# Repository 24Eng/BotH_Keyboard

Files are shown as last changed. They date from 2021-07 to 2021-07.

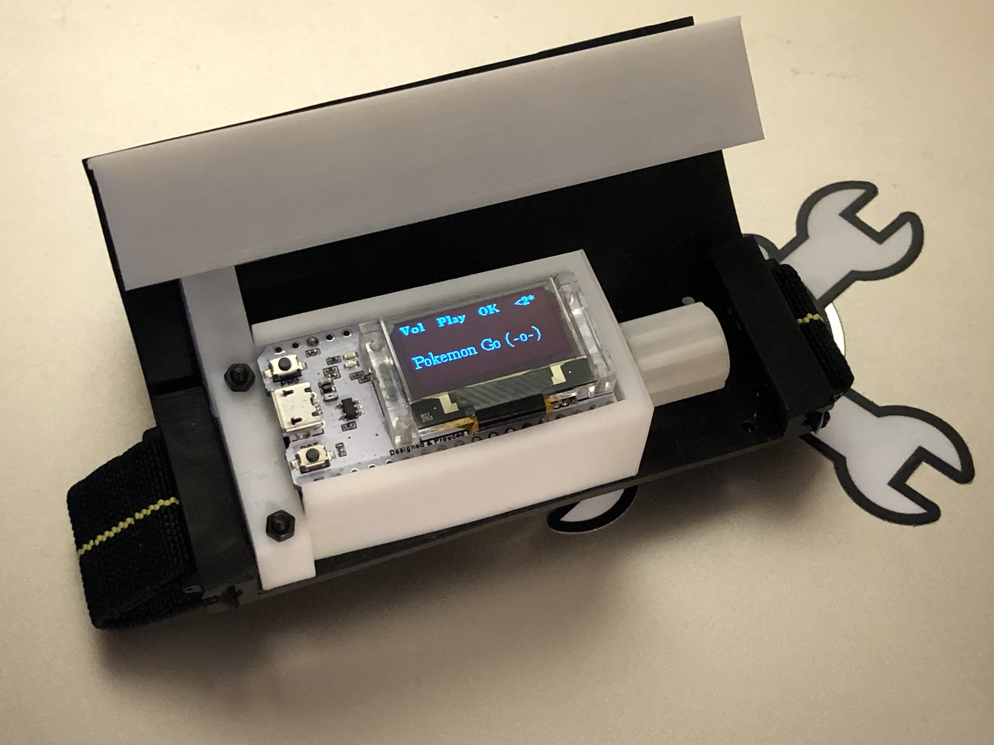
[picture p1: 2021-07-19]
2021-07-18 18.53.59.jpg

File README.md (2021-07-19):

# BotH_Keyboard
http://www.24hourengineer.com/search?q=%22BackOfTheHand%22&max-results=20&by-date=true

I use macros at work and home all the time, but sometimes pressing shift + alt + control + W or some other hard-to-remember combination isn't the best. Gamers have used off-hand keyboards for a while, and I love mine, but they're only helpful if you're at your battle station. I have seen folks put macro buttons on a footstool and use their toes, and that kind of ingenuity got me thinking. I wanted to keep my hands free and add wireless flexibility. Leveraging my experience with wearables, I got BOTH. 

The Back of the Hand keyboard gives me four programmable buttons by extending a finger backward. I can twist a screwdriver and pause the music on my phone or hold an electrical probe and command the computer to activate a test point.

Four is not a lot, so the wheel lets me change layers without fuss. I can go from obscure keyboard buttons to Pokemon Go (-o-) in a second. The case is entirely 3D printed. It accepts standard Cherry MX keyswitches so that you can choose clicky or silent operation. It uses an Apple Watch band so that you can choose any color. I like the black elastic, but the stainless Milanese looks sharp.

I would probably use a larger battery if I built a second one, but it is still possible to use this while connected to any USB charger. The core is an ESP32 and uses Bluetooth Low-Energy to emulate a keyboard.

My build log is at 24hourengineer.com. 

Helpful links and library sources
TTGO ESP32 module
https://github.com/Xinyuan-LilyGO/TTGO-T-Display

ESP32 module links
https://robotzero.one/heltec-wifi-kit-32/
https://github.com/Heltec-Aaron-Lee/WiFi_Kit_series

Display drivers
https://github.com/olikraus/u8g2

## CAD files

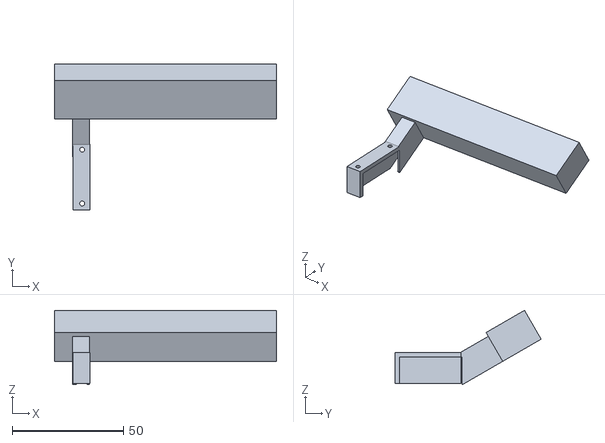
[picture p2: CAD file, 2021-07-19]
2021-07-15_WearableMacroKeyboard_Cover.stl
100.0 x 65.9 x 33.5

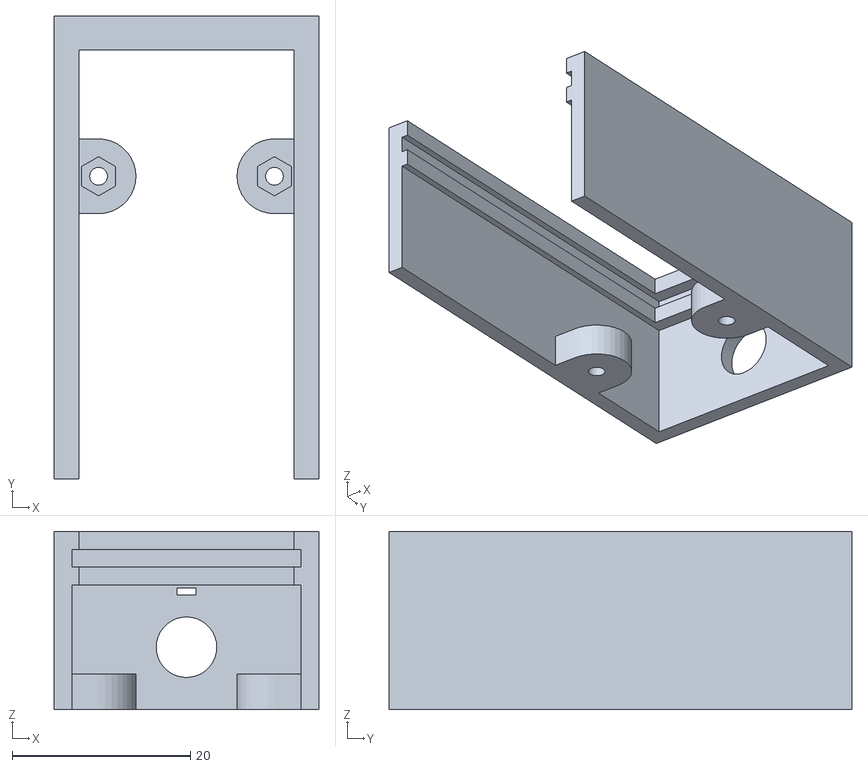
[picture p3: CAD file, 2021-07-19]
2021-06-22_BoardHolder.stl
29.8 x 52.0 x 20.0

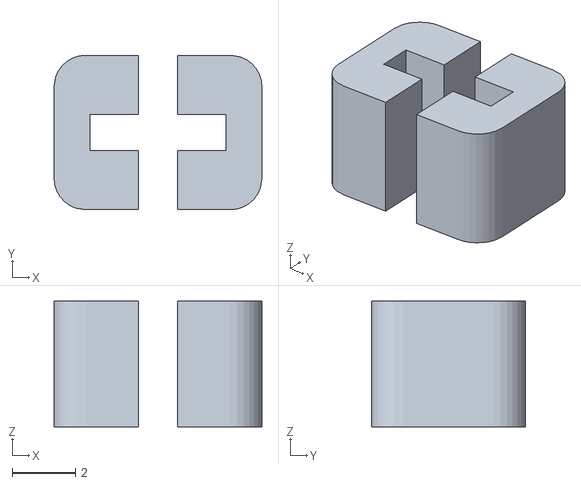
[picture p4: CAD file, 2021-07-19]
rsheldiii_keycap_stem.stl
6.60 x 4.90 x 3.99

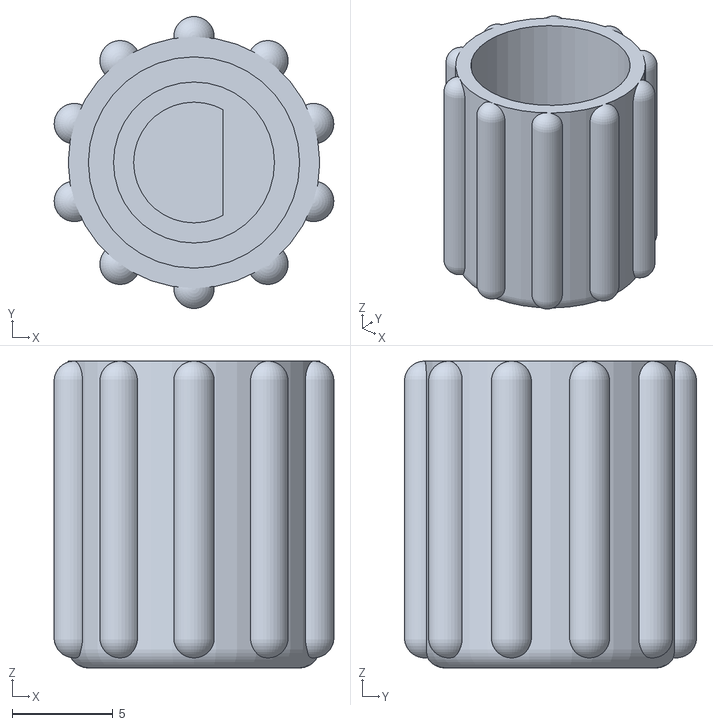
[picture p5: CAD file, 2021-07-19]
2021-06-22_EncoderKnob.stl
13.9 x 14.5 x 15.2

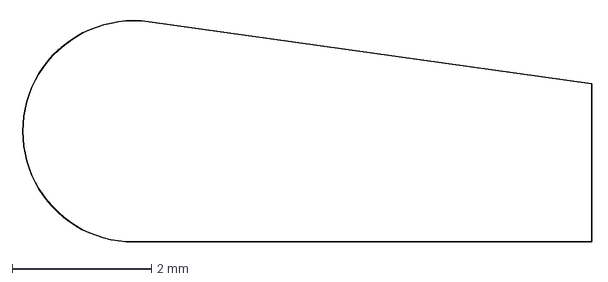
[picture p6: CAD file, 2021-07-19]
AppleWatchCavity.dxf
8.28 x 3.25 mm

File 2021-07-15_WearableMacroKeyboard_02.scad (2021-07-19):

// WearableMacroKeyboard by 24Eng
printSelection = 0;
thickness = 2;
platformThickness = 3;
palmWidth = 80;
fingerDistance = 25;
boltDiameter = 2;
boltHeadDiameter = 4.5;
boltHeadThickness = 1.5;
nutMajorDiameter = 4.4;
printerSlop = 0.1;
keyswitchHoleLength = 0.551 * 25.4;
keyswitchHoleWidth = 0.551 * 25.4;
keyswitchHoleThickness = 0.06 * 25.4;
keyswitchLength = 15.6;
keyswitchWidth = 15.6;
keyswitchThickness = 10;
watchBandLength = 31+thickness;
fingerPadSlope = 30;
keycapForwardDistance = 30;

BHLength = 50;
BHWidth = 25.75;
BHThickness = 2;
BHEdge = 0.8;
BHClearance = 12;
BHBoltDiameter = boltDiameter;
BHNutMajorDiameter = nutMajorDiameter;
BHMountOffset = 8;

boltRadius = boltDiameter/2 + printerSlop;
boltHeadRadius = boltHeadDiameter/2 + printerSlop;
nutMajorRadius = nutMajorDiameter / 2 + printerSlop;
platformWidth = (fingerDistance)*4;
platformLength = watchBandLength;
watchBandThickness = 8;


//$vpr = [70,0,55+360 * $t];
//$vpd = 150;
//$vpr = [55,0,25];
//$vpr = [90,0,0];
//$vpt = [0,0,10];
$fn=36;

if(printSelection == 0){
    color("powderblue"){
        // This platform portion touches the back of the palm (Metacarpals)
        MetacarpalPlatform();
        
        // This portion hovers over the fingers (proximal phalanges)
        ProximalPlatform();
        
//        // A cylinder at the joining area should keep the two platform halves from fracturing
//        translate([-platformWidth/2,platformLength/2,0]){
//            rotate([0,90,0]){
//                #cylinder(platformWidth, thickness/2, thickness/2);
//            }
//        }
        
    }
        // The board holder will support the microcontroller
    translate([-BHMountOffset,0,thickness/2]){
        rotate([0,0,270]){
            difference(){
                BoardHolder();
                translate([0,BHLength/2,BHClearance/2+BHThickness/2]){
                    rotate([90,0,0]){
                        EncoderHole();
                    }
                }
            }
        }
    }
    color("violet"){
        translate([-(BHWidth+BHMountOffset+watchBandThickness),-BHWidth/2-BHThickness,thickness/2]){
            difference(){
                translate([0,0,0]){
                    cube([platformWidth/2-BHWidth-BHMountOffset-watchBandThickness-0.5, BHWidth+BHThickness*2, BHClearance+BHThickness*1]);
                    translate([(platformWidth/-12),platformLength,thickness/2]){
                        rotate([fingerPadSlope,0,0]){
                            translate([0,keycapForwardDistance-12,0]){
                                difference(){
                                    cube([platformWidth, 20, 15]);
                                    translate([thickness,thickness,-0.01]){
                                        cube([platformWidth-thickness*2, 20-thickness*2, 15-thickness*2]);
                                    }
                                    translate([10,-2,0]){
                                        cube([platformWidth/2-BHWidth-BHMountOffset-watchBandThickness-1.5-thickness, thickness*3, BHClearance-thickness]);
                                    }
                                }
                            }
                        }
                    }
                    translate([(platformWidth/-12)+8,platformLength,thickness/2]){
                        rotate([fingerPadSlope,0,0]){
                            translate([0,-3,0]){
                                difference(){
                                    cube([platformWidth/2-BHWidth-BHMountOffset-watchBandThickness-0.5, BHWidth-4, BHClearance+1]);
                                   translate([thickness,0,0]){
                                       cube([platformWidth/2-BHWidth-BHMountOffset-watchBandThickness-1.5-thickness, BHWidth+BHThickness*1, BHClearance]);
                                   }
                                }
                            }
                        }
                    }
                }
                translate([(platformWidth/2-BHWidth-BHMountOffset-watchBandThickness)/2,thickness*1.5,0]){
                    cylinder(BHClearance*3, boltRadius, boltRadius, center=true);
                }
                translate([(platformWidth/2-BHWidth-BHMountOffset-watchBandThickness)/2,BHWidth+BHThickness*0.75,0]){
                    cylinder(BHClearance*3, boltRadius, boltRadius, center=true);
                }
                translate([thickness+0.01,thickness+0.01,0]){
                    cube([platformWidth/2-BHWidth-BHMountOffset-watchBandThickness-thickness, BHWidth*1.1, BHClearance]);
                }
            }
        }
    }
}

if(printSelection == 1){
    MetacarpalPlatform();
    ProximalPlatform();
}

if(printSelection == 2){
    color("violet"){
        translate([-(BHWidth+BHMountOffset+watchBandThickness),-BHWidth/2-BHThickness,thickness/2]){
            difference(){
                translate([0,0,0]){
                    cube([platformWidth/2-BHWidth-BHMountOffset-watchBandThickness-0.5, BHWidth+BHThickness*2, BHClearance+BHThickness*1]);
                    translate([(platformWidth/-12),platformLength,thickness/2]){
                        rotate([fingerPadSlope,0,0]){
                            translate([0,keycapForwardDistance-12,0]){
                                difference(){
                                    cube([platformWidth, 20, 15]);
                                    translate([thickness,thickness,-0.01]){
                                        cube([platformWidth-thickness*2, 20-thickness*2, 15-thickness*2]);
                                    }
                                    translate([10,-2,0]){
                                        cube([platformWidth/2-BHWidth-BHMountOffset-watchBandThickness-1.5-thickness, thickness*3, BHClearance-thickness]);
                                    }
                                }
                            }
                        }
                    }
                    translate([(platformWidth/-12)+8,platformLength,thickness/2]){
                        rotate([fingerPadSlope,0,0]){
                            translate([0,-3,0]){
                                difference(){
                                    cube([platformWidth/2-BHWidth-BHMountOffset-watchBandThickness-0.5, BHWidth-4, BHClearance+1]);
                                   translate([thickness,0,0]){
                                       cube([platformWidth/2-BHWidth-BHMountOffset-watchBandThickness-1.5-thickness, BHWidth+BHThickness*1, BHClearance]);
                                   }
                                }
                            }
                        }
                    }
                }
                translate([(platformWidth/2-BHWidth-BHMountOffset-watchBandThickness)/2,thickness*1.5,0]){
                    cylinder(BHClearance*3, boltRadius, boltRadius, center=true);
                }
                translate([(platformWidth/2-BHWidth-BHMountOffset-watchBandThickness)/2,BHWidth+BHThickness*0.75,0]){
                    cylinder(BHClearance*3, boltRadius, boltRadius, center=true);
                }
                translate([thickness+0.01,thickness+0.01,0]){
                    cube([platformWidth/2-BHWidth-BHMountOffset-watchBandThickness-thickness, BHWidth*1.1, BHClearance]);
                }
            }
        }
    }
}

if(printSelection == 3){
    difference(){
        BoardHolder();
        translate([0,BHLength/2,BHClearance/2+BHThickness/2]){
            rotate([90,0,0]){
                EncoderHole();
            }
        }
    }
}


// 24 Eng // Modules // 24 Eng // Modules // 24 Eng // Modules // 24 Eng // Modules 

module EncoderHole(){
    encoderShaftDiameter = 6.8;
    encoderShaftRadius = encoderShaftDiameter/2;
    encoderKeyWidth = 2.1;
    encoderKeyThickness = 0.8;
    encoderKeyOffset = 12.5/2;
    encoderPunctureDepth = 10;
    cylinder(encoderPunctureDepth, encoderShaftRadius, encoderShaftRadius, center=true);
    translate([0,encoderKeyOffset,0])cube([encoderKeyWidth,encoderKeyThickness,encoderPunctureDepth], center=true);
}

module CountersunkBolt(){
    cylinder(thickness*3, boltRadius, boltRadius, center=true);
    cylinder(thickness+0.001, boltHeadRadius, 0, center=true);
}
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

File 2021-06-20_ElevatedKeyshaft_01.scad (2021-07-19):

// The keycap stem is from rsheldii from their amazing
// keycap model.
// https://www.thingiverse.com/thing:468651


printSelector = 3;
shaftThickness = 7;
shaftHeight = 10;
boltDiameter = 2;
fingerPadDiameter = 15;
fingerPadThickness = 2;
nutMajorDiameter = 4.4;
nutThickness = 1.5;
washerThickness = 0.75;
keycapHeight = 14;
keycapAngle = 30;

nutMajorRadius = nutMajorDiameter/2;
fingerPadRadius = fingerPadDiameter/2;
boltRadius = boltDiameter/2;
shaftFillet = 1;
roundedShaftSide = shaftThickness - shaftFillet;
roundedShaftHeight = shaftHeight+1.001 - shaftFillet;
existingKeyshaftHeight = 3.99;

$fn = 36;
//$vpr = [70,0,25+$t*360];
$vpd = 100;
$vpt = [0,0,6];

if(printSelector == 0){
    color("red")KeyShaft();
    color("blue"){
        translate([0,0,existingKeyshaftHeight+shaftHeight+boltRadius+fingerPadThickness/2+fingerPadRadius/2]){
            rotate([180,0,0]){
                FingerPad();
            }
        }
    }
}

if(printSelector == 1){
    KeyShaft();
}

if(printSelector == 2){
    FingerPad();
}

if(printSelector == 3){
    RoundedKeycap(keycapHeight, keycapAngle);
}


// 24Eng // B.o.t.H. // Back of the Hand // Modules // 24Eng //
// 24Eng // B.o.t.H. // Back of the Hand // Modules // 24Eng //

module FingerPad(){
    cylinder(fingerPadThickness, fingerPadRadius, fingerPadRadius, center=true);
    rotate([0,0,0]){
        translate([shaftThickness/2+washerThickness,-fingerPadRadius/2,0]){
            difference(){
                translate([0,0,0]){
                    cube([fingerPadThickness, fingerPadRadius, fingerPadThickness/2+fingerPadRadius/2]);
                    translate([fingerPadThickness/2,fingerPadRadius/2,fingerPadRadius/2+fingerPadThickness/2]){
                        rotate([0,90,0]){
                            cylinder(fingerPadThickness, fingerPadRadius/2, fingerPadRadius/2, center=true);
                        }
                    }
                }
                translate([fingerPadThickness/2,fingerPadRadius/2,fingerPadRadius/2+fingerPadThickness/2]){
                    rotate([0,90,0]){
                        cylinder(fingerPadThickness*2, boltRadius, boltRadius, center=true);
                        translate([0,0,0])cylinder(nutThickness, nutMajorRadius, nutMajorRadius, $fn=6);
                    }
                }
            }
        }
    }
    rotate([0,0,180]){
        translate([shaftThickness/2+washerThickness,-fingerPadRadius/2,0]){
            difference(){
                translate([0,0,0]){
                    cube([fingerPadThickness, fingerPadRadius, fingerPadThickness/2+fingerPadRadius/2]);
                    translate([fingerPadThickness/2,fingerPadRadius/2,fingerPadRadius/2+fingerPadThickness/2]){
                        rotate([0,90,0]){
                            cylinder(fingerPadThickness, fingerPadRadius/2, fingerPadRadius/2, center=true);
                        }
                    }
                }
                translate([fingerPadThickness/2,fingerPadRadius/2,fingerPadRadius/2+fingerPadThickness/2]){
                    rotate([0,90,0]){
                        cylinder(fingerPadThickness*2, boltRadius, boltRadius, center=true);
                    }
                }
            }
        }
    }
}

module KeyShaft(){
    import("rsheldiii_keycap_stem.stl", convexity=10);
    difference(){
        translate([0,0,existingKeyshaftHeight + shaftHeight/2+boltDiameter*0.75]){
            minkowski(){
                cube([roundedShaftSide, roundedShaftSide, roundedShaftHeight+boltDiameter*1.5], center=true);
                cylinder(0.01, shaftFillet/2, shaftFillet/2, center=true);
            }
        }


        translate([0,0,existingKeyshaftHeight+shaftHeight+boltRadius]){
            rotate([0,90,0]){
                cylinder(shaftThickness*2, boltRadius, boltRadius, center=true);
            }
        }
    }
}

module RoundedKeycap(RKHeight, RKAngle){
    keyswitchSideLength = 15.6;
    keycapSideLength = keyswitchSideLength + 2*2;
    RKCavityDepth = 6.6 + 3.6 - 3.99;
    RKThickness = 2;
    RKRounding = 2;
    RKCylinderRadius = keyswitchSideLength/2;
    import("rsheldiii_keycap_stem.stl", convexity=10);
    difference(){
        translate([0,0,-RKCavityDepth/2+existingKeyshaftHeight+RKThickness]){
            minkowski(){
                cube([keycapSideLength, keycapSideLength, RKCavityDepth], center=true);
                sphere(RKRounding);
            }
        }
        translate([0,0,-RKCavityDepth/2+existingKeyshaftHeight-RKRounding/2]){
            minkowski(){
                cube([keycapSideLength-RKThickness, keycapSideLength-RKThickness, RKCavityDepth], center=true);
                sphere(RKRounding/2);
            }
        }
    }
    minkowski(){
        difference(){
            translate([0,0,existingKeyshaftHeight+RKRounding]){
                cylinder(RKHeight+RKCylinderRadius, RKCylinderRadius, RKCylinderRadius, center=false);
            }
            translate([0,0,existingKeyshaftHeight + RKHeight + RKCylinderRadius]){
                rotate([RKAngle,0,0]){
                    cube([RKCylinderRadius*6, RKCylinderRadius*6, RKCylinderRadius*2], center=true);
                }
            }
        }
        sphere(RKRounding);
    }
}





        translate([0,0,0]){
            
        }

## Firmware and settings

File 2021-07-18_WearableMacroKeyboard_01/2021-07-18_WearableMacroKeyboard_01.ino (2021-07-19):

// 24 Hour Engineer
// Brian McEvoy
// https://www.24hourengineer.com/

// This code was tested on "Heltec WiFi Kit 32"
// https://robotzero.one/heltec-wifi-kit-32/
// https://www.amazon.com/KeeYees-Internet-Development-Display-Bluetooth/dp/B07THGMMV8

// The Bluetooth keyboard library comes from
// https://github.com/T-vK/ESP32-BLE-Keyboard

// The accelerometer library is from good ole' Adafruit
// https://learn.adafruit.com/adafruit-lis3dh-triple-axis-accelerometer-breakout/arduino

#include <BleKeyboard.h>
BleKeyboard bleKeyboard("BackOfTheHand Keyboard", "24Eng", 100);

#include <Arduino.h>
#include <U8g2lib.h>

#ifdef U8X8_HAVE_HW_SPI
#include <SPI.h>
#endif
#ifdef U8X8_HAVE_HW_I2C
#include <Wire.h>
#endif

U8G2_SSD1306_128X64_NONAME_F_SW_I2C u8g2(U8G2_R0, /* clock=*/ 15, /* data=*/ 4, /* reset=*/ 16);

// Add the libraries exclusive to the accelerometer
// Some of the previous libraries are also necessary
#include <Adafruit_LIS3DH.h>
#include <Adafruit_Sensor.h>
Adafruit_LIS3DH lis = Adafruit_LIS3DH();

#include <EEPROM.h>
/*
Each setting gets its own EEPROM address for non-volatile storage, even bools
Usage:      EEPROM.write(addr, val);

  Table
EEPROM.write(0, vibrationSetting);
EEPROM.write(1, audioSetting);
EEPROM.write(2, screenTimeout);
EEPROM.write(3, volumeAdjustmentFactor);
EEPROM.write(4, diagnosticPrintBit);
EEPROM.write(5, AppleProducts);
 */

int keyswitchLocations[] = {36, 37, 38, 39};
int encoderPinLocations[] = {34, 35, 32};
int vibratorPin = 23;
int piezoElementPin = 19;

bool startupBit = true;
bool diagnosticPrintBit = HIGH;
bool oldReading[4];
bool currentState[4];
bool risingEdge[4];
bool fallingEdge[4];
long cooldownTimer[5];
int cooldownWait = 100;
int encoderPinLevels[4];
bool encoderPinStates[4];
bool encoderUntriggered = HIGH;
bool encoderButtonUntriggered = HIGH;
int currentLayer = 2;
int totalLayers = 7;  // This is zero-justified
String layerNames[] = {"Settings 1", "Settings 2", "Media Control", "Work Macros", "Function Keys", "More F Keys", "Pokemon Go (-o-)", "Repeating Functions"};
String layerKeys[] = {
  "Vib    Snd    Scrn   Vol*",
  "BT    SrlDiag    OS      --",
  "Vol    Bk     Fwd    Play",
  "Vol+  Vol-    F24     Rtn",
  "F21     F22     F23     F24",
  "F17     F18     F19     F20",
  "Vol    Play    OK     <2*",
  "F5      //     Ctrl     rPlay"};
bool vibratingSettingBit = HIGH;
bool piezoSettingBit = HIGH;
long oldAccelerometerPosition;
long newAccelerometerPosition;
int volumeAdjustmentFactor = 3; // A phone OS can use 1, but a computer should use 3
bool suppressBuzzer = LOW;
bool vibrationSetting = HIGH;
bool audioSetting = HIGH;
int screenTimeout = 10;
bool BTStatus = HIGH;
long screenSleepTimer = 20000;
bool screenBlanked = LOW;
bool AppleProducts = HIGH;
long repeatingCooldownTimeout = 0;
int repeatingIntervalMultiplier = 0;
int repeatingIntervalMillis = 0;
int repeatingKeySequence = 5; // This just has to be larger than the number of keyswitches



void setup() {
  
  // Set the discrete inputs to use internal PULLUP resistors. It is still
  // safe to add physical resistors.
  for(int i=0; i<4; i++){
    pinMode(keyswitchLocations[i], INPUT);
  }
    
  for(int i=0; i<3; i++){
    pinMode(encoderPinLocations[i], INPUT_PULLUP);
  }
  // Set the outputs as such
  pinMode(vibratorPin, OUTPUT);
  pinMode(piezoElementPin, OUTPUT);
  
  
  u8g2.begin();
  u8g2.clearBuffer();          // clear the internal memory
  u8g2.setFont(u8g2_font_ncenB08_tr); // choose a suitable font
  u8g2.drawStr(25,20,"B.o.t.H."); // write something to the internal memory
  u8g2.drawStr(0,40,"Back of the hand.");  // write something to the internal memory
  u8g2.sendBuffer();          // transfer internal memory to the display
  
  Serial.begin(115200);
//  mySerial.begin(piezoFrequency);
//  mySerial.print("Hello, world");
  
  if (! lis.begin(0x18)) {   // change this to 0x19 for alternative i2c address
    Serial.println("Couldnt start");
    while (1) yield();
  }
  Serial.println("Accelerometer found!");
  Serial.print("Data rate set to: ");
  switch (lis.getDataRate()) {
    case LIS3DH_DATARATE_1_HZ: Serial.println("1 Hz"); break;
    case LIS3DH_DATARATE_10_HZ: Serial.println("10 Hz"); break;
    case LIS3DH_DATARATE_25_HZ: Serial.println("25 Hz"); break;
    case LIS3DH_DATARATE_50_HZ: Serial.println("50 Hz"); break;
    case LIS3DH_DATARATE_100_HZ: Serial.println("100 Hz"); break;
    case LIS3DH_DATARATE_200_HZ: Serial.println("200 Hz"); break;
    case LIS3DH_DATARATE_400_HZ: Serial.println("400 Hz"); break;

    case LIS3DH_DATARATE_POWERDOWN: Serial.println("Powered Down"); break;
    case LIS3DH_DATARATE_LOWPOWER_5KHZ: Serial.println("5 Khz Low Power"); break;
    case LIS3DH_DATARATE_LOWPOWER_1K6HZ: Serial.println("16 Khz Low Power"); break;
  }
//  screenName(layerKeys[currentLayer], layerNames[currentLayer]);
  EEPROM.begin(512);
  // Recall settings stored in EEPROM
  vibrationSetting = EEPROM.read(0);
  audioSetting = EEPROM.read(1);
  screenTimeout = EEPROM.read(2);
  volumeAdjustmentFactor = EEPROM.read(3);
  diagnosticPrintBit = EEPROM.read(4);
  AppleProducts = EEPROM.read(5);
  if(diagnosticPrintBit){
    Serial.print("Vibration: ");
    Serial.print(EEPROM.read(0));
    Serial.print("\n");
    
    Serial.print("Audio: ");
    Serial.print(EEPROM.read(1));
    Serial.print("\n");
    
    Serial.print("Timeout: ");
    Serial.print(EEPROM.read(2));
    Serial.print("\n");
    
    Serial.print("Volume*: ");
    Serial.print(EEPROM.read(3));
    Serial.print("\n");
    
    Serial.print("Printbit: ");
    Serial.print(EEPROM.read(4));
    Serial.print("\n");
    
    Serial.print("App/Win: ");
    Serial.print(EEPROM.read(5));
    Serial.print("\n");
  }
}

void loop(){
  if(startupBit && scanKeyswitches()){
    bleKeyboard.begin();
    startupBit = LOW;
    u8g2.clearBuffer();
  }
  if(scanKeyswitches()){
    screenSleepTimer = millis() + screenTimeout*1000;
    screenBlanked = LOW;
    layerTyping();
  }
  if(currentLayer == 7){
    repeatingKeystrokes();
  }
  if(scanEncoder()){
    repeatingKeySequence = 5;
    screenSleepTimer = millis() + screenTimeout*1000;
    screenBlanked = LOW;
  }
  if((millis() > screenSleepTimer) && !screenBlanked){
    screenBlanked = HIGH;
    blankScreen();
  }
}

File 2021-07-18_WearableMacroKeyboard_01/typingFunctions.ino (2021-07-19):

void layerTyping(){
  switch (currentLayer){
    case 0:
      // Settings, page 1
      if (risingEdge[3] == 1){
        vibrationSetting = !vibrationSetting;
        EEPROM.write(0, vibrationSetting);
        EEPROM.commit();
        if(diagnosticPrintBit){
          Serial.print("Vibration: ");
          Serial.print(vibrationSetting);
          Serial.print("\n");
        }
      }
      if (risingEdge[2] == 1){
        audioSetting = !audioSetting;
        EEPROM.write(1, audioSetting);
        EEPROM.commit();
        if(diagnosticPrintBit){
          Serial.print("Sound: ");
          Serial.print(audioSetting);
          Serial.print("\n");
        }
      }
      if (risingEdge[1] == 1){
        screenTimeout = screenTimeout + 5;
        if (screenTimeout > 30){
          screenTimeout = 10;
        }
        EEPROM.write(2, screenTimeout);
        EEPROM.commit();
      }
      if (risingEdge[0] == 1){
        volumeAdjustmentFactor++;
        if (volumeAdjustmentFactor > 5){
          volumeAdjustmentFactor = 1;
        }
        EEPROM.write(3, volumeAdjustmentFactor);
        EEPROM.commit();
        if(diagnosticPrintBit){
          Serial.print("Volume adjustment factor: ");
          Serial.print(volumeAdjustmentFactor);
          Serial.print("\n");
        }
      }
      screenName(layerKeys[currentLayer], layerNames[currentLayer]);
      break;
    case 1:
      // Settings, page 1
      if (risingEdge[3] == 1){
        btStop();
        BTStatus = LOW;
      }
      if (risingEdge[2] == 1){
        diagnosticPrintBit = !diagnosticPrintBit;
        EEPROM.write(4, diagnosticPrintBit);
        EEPROM.commit();
        Serial.print("Diagnostic print statements: ");
        Serial.print(diagnosticPrintBit);
        Serial.print("\n");
      }
      if (risingEdge[1] == 1){
        AppleProducts = !AppleProducts;
        EEPROM.write(5, AppleProducts);
        EEPROM.commit();
      }
      if (risingEdge[0] == 1){
        screenName(layerKeys[currentLayer], layerNames[currentLayer]);
      }
      screenName(layerKeys[currentLayer], layerNames[currentLayer]);
      break;
    case 2:
      // Media control mode
      if (risingEdge[3] == HIGH){
        sensors_event_t event;
        lis.getEvent(&event);
        newAccelerometerPosition = (event.acceleration.y);
        oldAccelerometerPosition = newAccelerometerPosition;
        suppressBuzzer = HIGH;
      }
      if(currentState[3] && (millis() > cooldownTimer[4])){
        cooldownTimer[4] = millis() + 10;
        sensors_event_t event;
        lis.getEvent(&event);
        
        newAccelerometerPosition = (event.acceleration.y);
        if(newAccelerometerPosition < oldAccelerometerPosition){
          for(int i=0; i<volumeAdjustmentFactor; i++){
            bleKeyboard.write(KEY_MEDIA_VOLUME_DOWN);
          }
        }
        if(newAccelerometerPosition > oldAccelerometerPosition){
          for(int i=0; i<volumeAdjustmentFactor; i++){
            bleKeyboard.write(KEY_MEDIA_VOLUME_UP);
          }
        }
        oldAccelerometerPosition = newAccelerometerPosition;
      }
      if(fallingEdge[3] == HIGH){
        suppressBuzzer = LOW;
      }
      if (risingEdge[2] == 1){
        bleKeyboard.write(KEY_MEDIA_PREVIOUS_TRACK);
      }
      if (risingEdge[1] == 1){
        bleKeyboard.write(KEY_MEDIA_NEXT_TRACK);
      }
      if (risingEdge[0] == 1){
        bleKeyboard.write(KEY_MEDIA_PLAY_PAUSE);
      }
      screenName(layerKeys[currentLayer], layerNames[currentLayer]);
      break;
    case 3:
      // Work macros mode
      if (risingEdge[3] == 1){
        bleKeyboard.write(KEY_MEDIA_VOLUME_UP);
      }
      if (risingEdge[2] == 1){
        bleKeyboard.write(KEY_MEDIA_VOLUME_DOWN);
      }
      if (risingEdge[1] == 1){
        bleKeyboard.write(KEY_F24);
      }
      if (risingEdge[0] == 1){
        bleKeyboard.write(KEY_RETURN);
      }
      screenName(layerKeys[currentLayer], layerNames[currentLayer]);
      break;
    case 4:
      // Function keys F21 - F24
      if (risingEdge[3] == 1){
        bleKeyboard.write(KEY_F21);
      }
      if (risingEdge[2] == 1){
        bleKeyboard.write(KEY_F22);
      }
      if (risingEdge[1] == 1){
        bleKeyboard.write(KEY_F23);
      }
      if (risingEdge[0] == 1){
        bleKeyboard.write(KEY_F24);
      }
      screenName(layerKeys[currentLayer], layerNames[currentLayer]);
      break;
    case 5:
      // Function keys F17 - F20
      if (risingEdge[3] == 1){
        bleKeyboard.write(KEY_F17);
      }
      if (risingEdge[2] == 1){
        bleKeyboard.write(KEY_F18);
      }
      if (risingEdge[1] == 1){
        bleKeyboard.write(KEY_F19);
      }
      if (risingEdge[0] == 1){
        bleKeyboard.write(KEY_F20);
      }
      screenName(layerKeys[currentLayer], layerNames[currentLayer]);
      break;
    case 6:
      // Pokémon Go but shown on the screen as "Pokemon Go" without the accent mark
      if (risingEdge[3] == HIGH){
        sensors_event_t event;
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
